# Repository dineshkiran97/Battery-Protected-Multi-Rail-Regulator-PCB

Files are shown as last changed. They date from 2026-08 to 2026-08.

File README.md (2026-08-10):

# Battery-Protected Multi-Rail Regulator PCB

KiCad project for a battery-powered linear regulator board that generates two
regulated rails (5V and 3.3V) from a single-cell battery input, with reverse-polarity
protection and a power-on indicator.

## Overview

- **Input:** Single-cell battery via a 2-pin JST PH connector (J1)
- **Protection:** Series Schottky diode (D1, 1N5820) blocks reverse-polarity connection
- **Outputs:** Two independently regulated rails
  - 3.3V via U1 (LDL1117S33R)
  - 5.0V via U2 (LDL1117S50R)
- **Indicator:** Power-on LED (D2, LTST-C171KGKT) with current-limiting resistor (R1, 255Ω)
- **Breakout:** 4-pin header (J3) exposing BAT / 5V / 3.3V / GND for downstream boards
- **Layout:** 2-layer PCB, fully routed (0 unrouted nets), DRC clean (0 errors)

## Schematic

| Ref | Part | Function |
|---|---|---|
| U1 | LDL1117S33R | 3.3V fixed LDO regulator (SOT-23-5) |
| U2 | LDL1117S50R | 5.0V fixed LDO regulator (SOT-23-5) |
| D1 | 1N5820 | Schottky diode, reverse-polarity protection |
| D2 | LTST-C171KGKT | Power-on indicator LED |
| R1 | 255Ω | LED current-limiting resistor |
| C1, C2 | 1µF (0805) | Input decoupling caps |
| C3, C4 | 4.7µF (0805) | Output decoupling caps |
| J1 | B2B-PH-K-S | 2-pin battery input connector |
| J2 | PC712A | Auxiliary connector/switch |
| J3 | Conn_01x04 | 4-pin breakout header (BAT/5V/3.3V/GND) |

Full details in [`hardware/BOM.csv`](hardware/BOM.csv).

## Repository structure

```
.
├── README.md
├── LICENSE
├── .gitignore
├── hardware/
│   ├── VLO.kicad_pro
│   ├── VLO.kicad_sch
│   ├── VLO.kicad_pcb
│   └── BOM.csv
├── production/
│   ├── gerbers/
│   ├── BOM.csv
│   └── pos.csv
└── images/
    ├── schematic.png
    ├── pcb-layout.png
    └── pcb-3d.png
```

Drop your `.kicad_pro` / `.kicad_sch` / `.kicad_pcb` files into `hardware/`, and export
Gerbers + a top-view PCB screenshot into `production/` and `images/` respectively.

## Design notes

- D1 sits in series between the battery connector and the BAT rail, so a reversed
  battery simply doesn't power the board instead of damaging U1/U2.
- Input caps are 1µF and output caps are 4.7µF per regulator, per the LDL1117
  datasheet's minimum stability requirements.
- DRC was run with **0 errors**; a small number of warnings remain (silkscreen
  clearance on densely packed 0805 footprints) and are cosmetic, not functional.

## Status

- [x] Schematic capture
- [x] Footprint assignment
- [x] 2-layer routing (0 unrouted nets)
- [x] DRC (0 errors)
- [ ] Gerbers exported / fab-ready

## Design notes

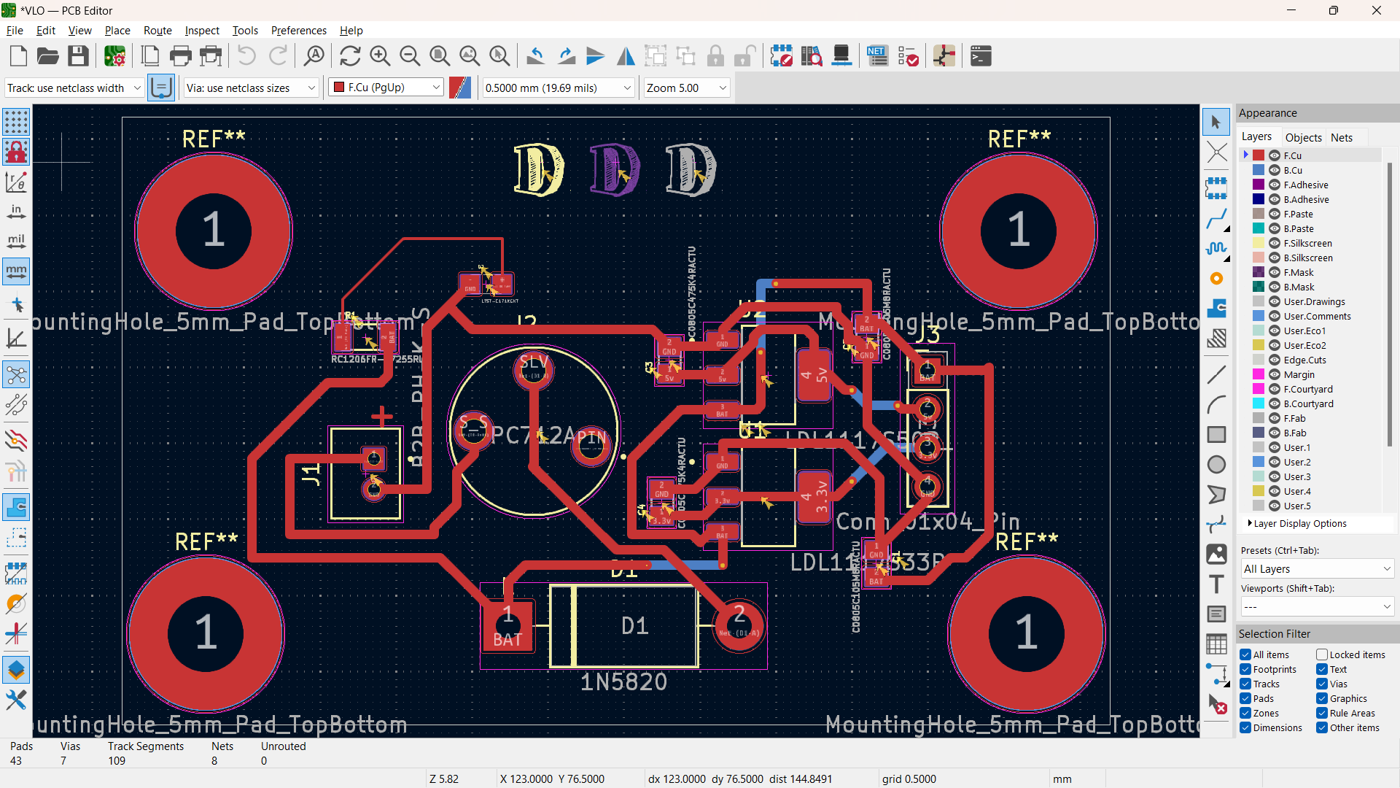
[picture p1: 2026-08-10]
images/pcb-layout.png

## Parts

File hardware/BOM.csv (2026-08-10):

Reference | Value | Footprint | Description | Qty
U1 | LDL1117S33R | SOT-23-5 | 3.3V fixed LDO regulator | 1
U2 | LDL1117S50R | SOT-23-5 | 5.0V fixed LDO regulator | 1
D1 | 1N5820 | SOD-123 | Schottky diode - reverse polarity protection | 1
D2 | LTST-C171KGKT | 0603 LED | Power-on indicator LED | 1
R1 | 255R | 1206 | LED current-limiting resistor | 1
C1 | 1uF | 0805 | Input decoupling capacitor (U2 5V rail) | 1
C2 | 1uF | 0805 | Input decoupling capacitor (U1 3.3V rail) | 1
C3 | 4.7uF | 0805 | Output decoupling capacitor (U2 5V rail) | 1
C4 | 4.7uF | 0805 | Output decoupling capacitor (U1 3.3V rail) | 1
J1 | B2B-PH-K-S | JST PH 2-pin | Battery input connector | 1
J2 | PC712A | TBD - confirm part function | Auxiliary connector/switch | 1
J3 | Conn_01x04 | 2.54mm header | Breakout header: BAT/5V/3.3V/GND | 1

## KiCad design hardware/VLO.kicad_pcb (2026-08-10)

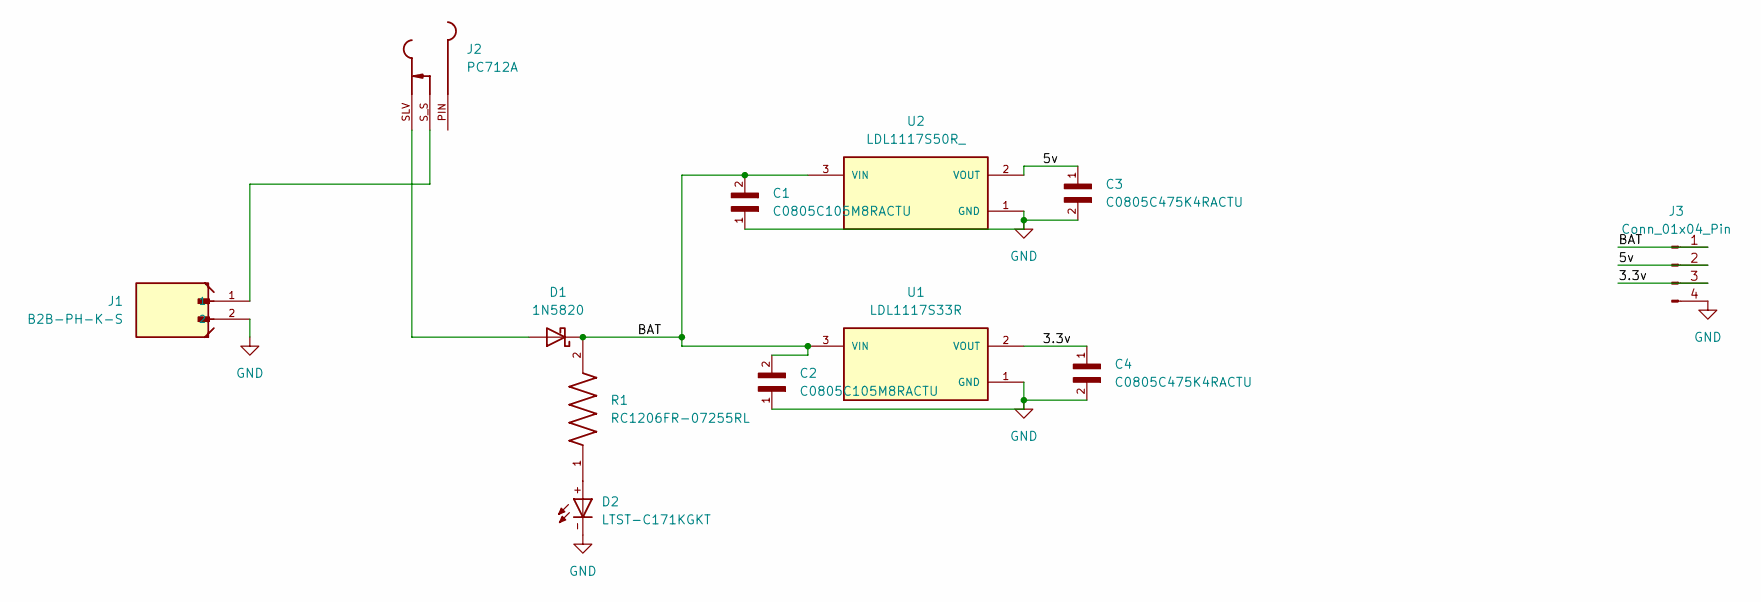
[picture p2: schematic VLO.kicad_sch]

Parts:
C1, C2: C0805C105M8RACTU; CAPC2012X100N
C3, C4: C0805C475K4RACTU; CAPC2012X88N
D1: 1N5820; D_DO-201AD_P15.24mm_Horizontal
D2: LTST-C171KGKT; DIOC200X125X110
J1: B2B-PH-K-S; JST_B2B-PH-K-S
J2: PC712A; SWITCHCRAFT_PC712A; PARTREV G; DigiKey_Part_Number SC1050-ND
J3: Conn_01x04_Pin; PinHeader_1x04_P2.54mm_Vertical
R1: RC1206FR-07255RL; RESC3116X65N
U1: LDL1117S33R; SOT230P700X180-4N; PARTREV 7
U2: LDL1117S50R_; SOT230P700X180-4N; PARTREV 7

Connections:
/3.3v: C4.1, J3.3, U1.2 (VOUT), U1.4 (VOUT)
/5v: C3.1, J3.2, U2.2 (VOUT), U2.4 (VOUT)
/BAT: C1.2, C2.2, D1.1 (K), J3.1, R1.2, U1.3 (VIN), U2.3 (VIN)
GND: C1.1, C2.1, C3.2, C4.2, D2.-, J1.2, J3.4, U1.1 (GND), U2.1 (GND)
unnamed: D1.2 (A), J2.SLV
unnamed: D2.+, R1.1
unnamed: J1.1, J2.S_S

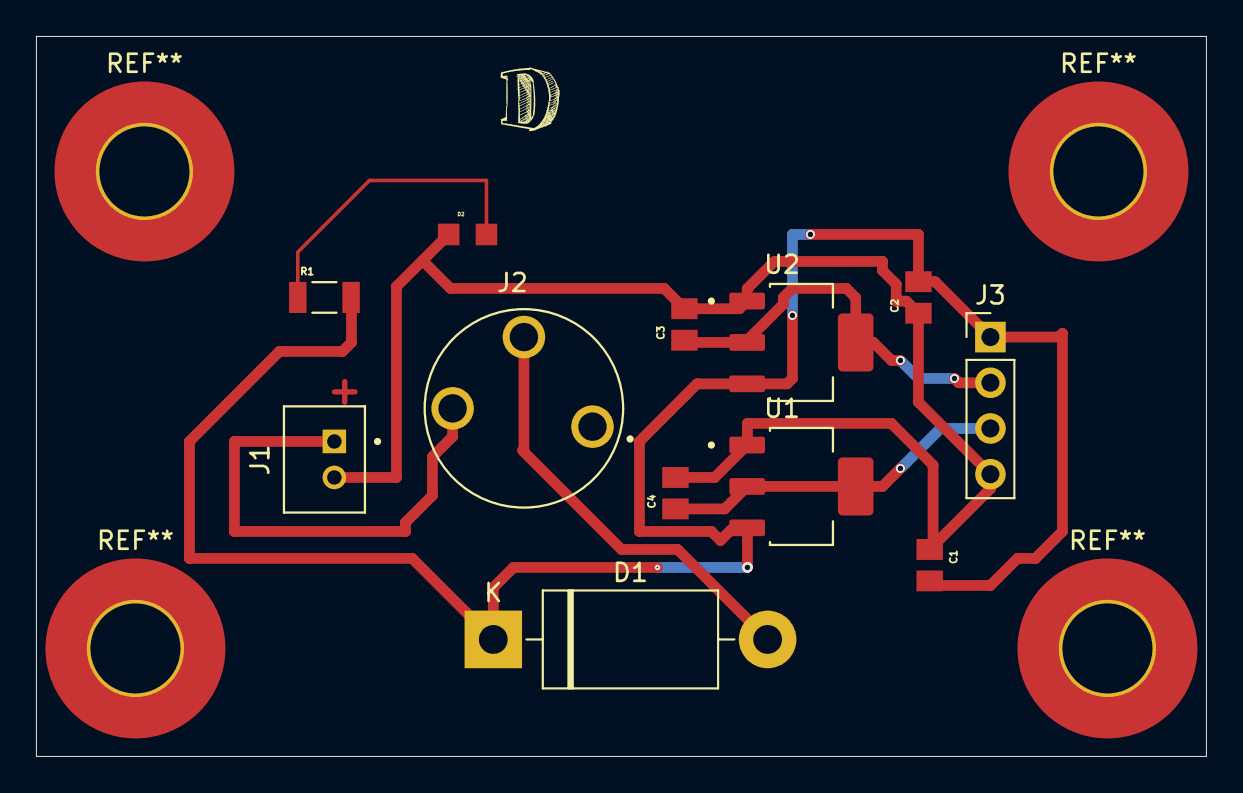
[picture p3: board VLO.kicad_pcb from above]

Board: 2 copper layers, 65.0 x 40.0 mm, 12 parts (0 on the bottom side), 7 nets.

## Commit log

2026-08-10 Initial project commit
    [B2B-PH-K-S.step, BOM.csv, C0805C105M8RACTU.step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]
2026-08-10 Added initial project files and folder structure
    [B2B-PH-K-S.step, BOM.csv, C0805C105M8RACTU.step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]
